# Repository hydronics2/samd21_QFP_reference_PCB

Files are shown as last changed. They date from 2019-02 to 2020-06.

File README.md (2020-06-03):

# samd21_QFP_reference_PCB

This is a reference design for a SAMD21 for easy SWD programming and testing.  This layout should work with any SAMD21 QFP package. The QFP package is pretty easy to solder and gives you about the same amount of pins as the original Aruduino 328P. The following SAMD21 packages are QFP:
- SAMD21E15 32kB of Flash **(read this)
- SAMD21E16 64kB of flash **(read this)
- SAMD21E17 128kB of flash
- SAMD21E18 256kB of flash

I made a specific reference board for the SAMD21G [posted here](https://github.com/hydronics2/2020-samd21_QFP_Reference) used in the Adafruit ItsyBitsy M0.

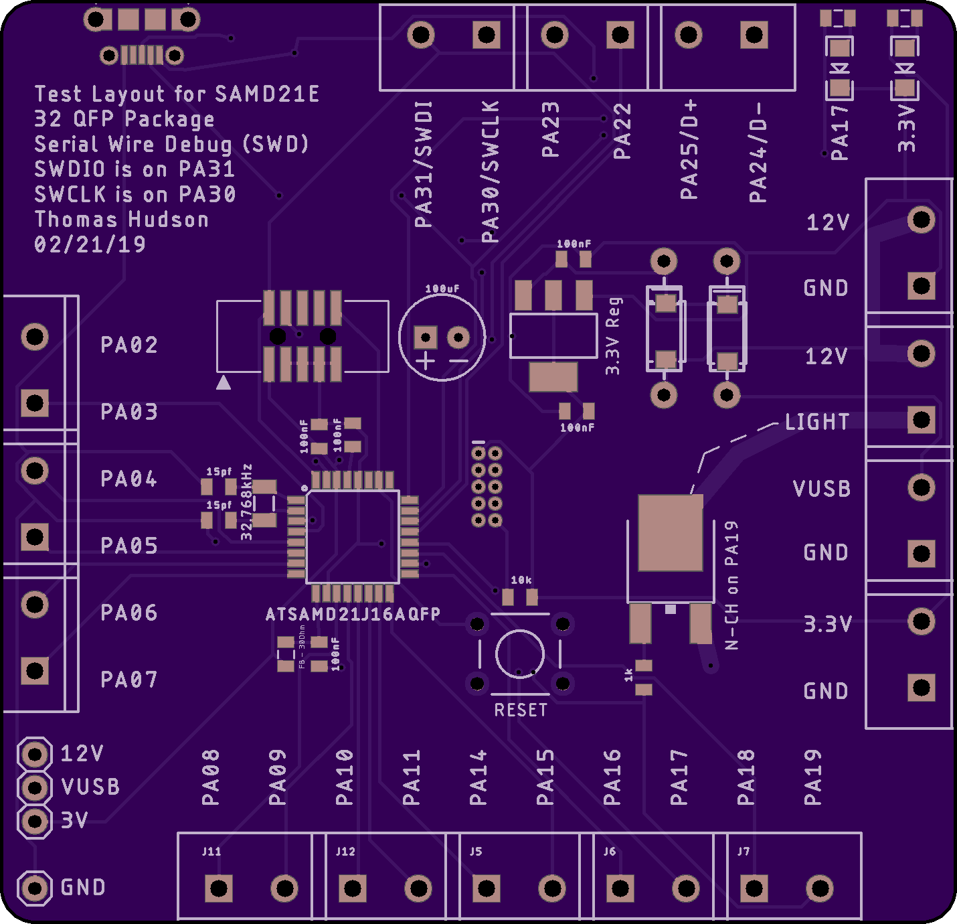
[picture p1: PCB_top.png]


I wanted to start to try SWD programming and these are the less expensive version of the popular SAMD21G on Adafruit and Sparkfun boards.
This PCB design relies heavily on Adafruit and Sparkfun reference design. I realized Adafruit has a similar design for their [32pin Trinket](https://learn.adafruit.com/assets/45723). They do not have a 32.768 crystal or a ferrite bead as recommended by Atmel. Not sure why/how that works. Instead of running the two pins PA00/PA01 to a crystal, they run them to their Dotstar LED!

You can order boards from Oshpark using this link: [project](https://oshpark.com/shared_projects/EjZP7lWQ)

Here's a list of parts:

- ATSAMD21E15B from [digikey](https://www.digikey.com/product-detail/en/microchip-technology/ATSAMD21E15B-AFT/1611-ATSAMD21E15B-AFTCT-ND/6832773). Don't get the ATSAMD21E15L!... the pinout is slightly different.
- generic 10 pin SWD Header from [mouser](https://www.mouser.com/ProductDetail/485-752)
- generic 5.08mm pitch screw headers (or 5mm)
- 	FIXED IND 10UH 500MA 300 MOHM [digikey](https://www.digikey.com/product-detail/en/tdk-corporation/MLZ2012N100LT000/445-6762-1-ND/2523583)
- 3.3V Regulator (18V max input) [mouser](https://www.mouser.com/ProductDetail/511-LDL1117S50R)
- T0-252-3 Mosfet (not needed) [mouser](https://www.mouser.com/ProductDetail/ON-Semiconductor-Fairchild/FDD8780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)
- USB micro connector [digikey](https://www.digikey.com/product-detail/en/amphenol-icc-fci/10118194-0001LF/609-4618-1-ND/2785382)
- standard 6mmx6mm tactile button [sparkfun](https://www.sparkfun.com/products/97)
- screw terminal 5mm pitch [sparkfun](https://www.sparkfun.com/products/8432) or [aliexpress](https://www.aliexpress.com/wholesale?catId=0&initiative_id=SB_20190221221755&SearchText=pcb+screw+terminal)
- input protection diodes on the 12V and USB input into the regulator. This is Adafruit's design. [digikey](https://www.digikey.com/product-detail/en/diodes-incorporated/B130-13-F/B130-FDICT-ND/815318)
- 32.768khz crystal (if needed, see above trinket design) [digikey](https://www.digikey.com/product-detail/en/epson/FC-135-32.7680KA-AG3/SER4086DKR-ND/6132726)
- crystal capacitors C7/C8 based on a 7pf load from the above crystal and assumed 2pf stray capacitence, CX1 = CX2 = 2(7pF - 2pF) = 10pF [digikey](https://www.digikey.com/product-detail/en/wurth-electronics-inc/885012006051/732-7793-1-ND/5454420)

SWD Programmer/Debugger: [Segger](https://www.digikey.com/product-detail/en/segger-microcontroller-systems/8.08.91-J-LINK-EDU-MINI/899-1061-ND/7387472)

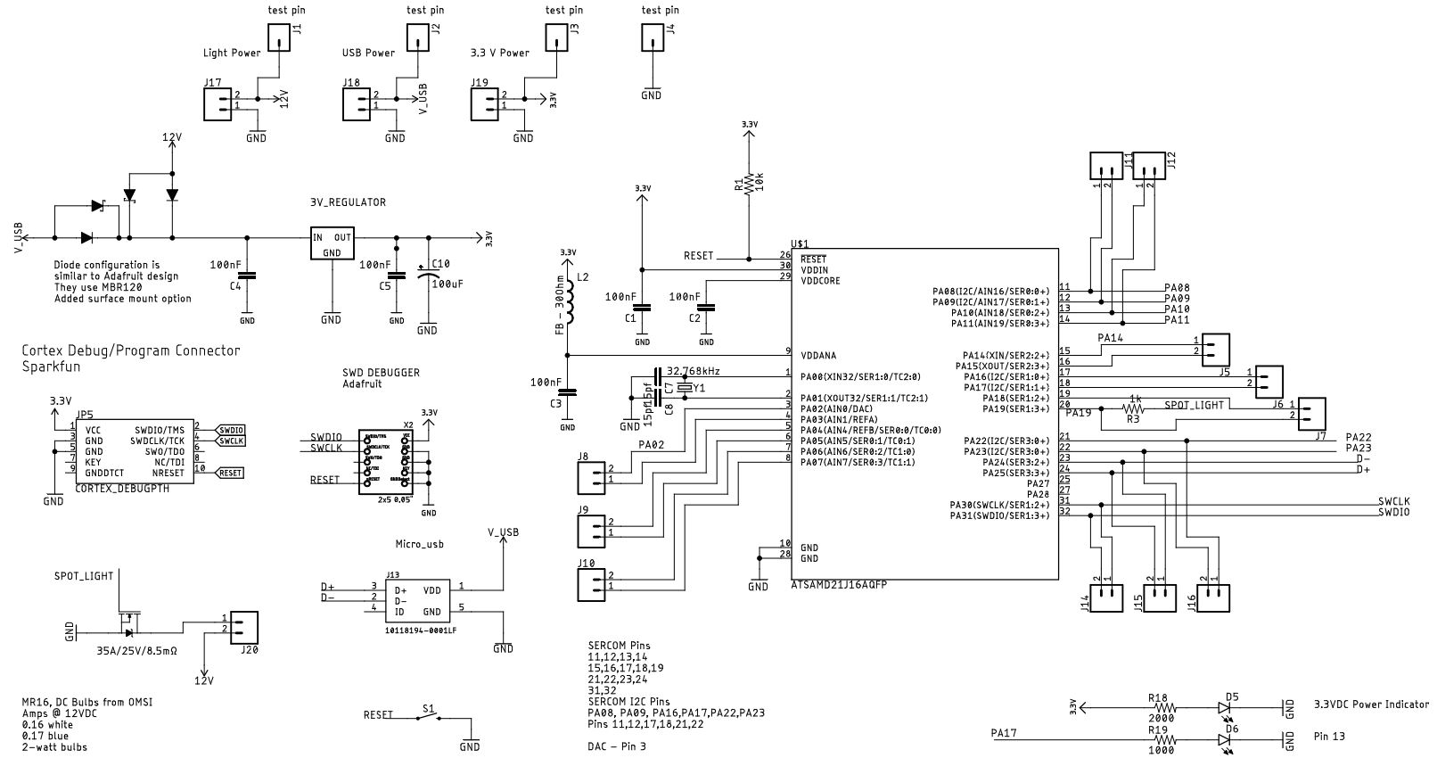
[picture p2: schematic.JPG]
schematic


Notes:
- add a ground plane
- chagne the silkscreen to SAMD21E15
- change the silkscreen C7/C8 from 15pf to 10pf

**READ THIS

The SAMD21E15 only has 32kb of flash. Fine for 8bit architecture but not for 32bit SAMD21 architecture!!
About 50 lines of simple code uses 332 bytes (12%) in for the UNO but compiles over 9,000 bytes (9248 bytes (56%)) for the SAMD21E15, SAMD21E16, SAMD21E17, etc

That means that I should have gone with the SAMD21E17 or SAMD21E18 with 128 or 256kb respectively.

[westf wrote this on the Arduino forum](https://forum.arduino.cc/index.php?topic=602377.msg4091161#msg4091161)... That's not as bad as it sounds - a sketch has a fair about of "fixed overhead" (an empty Zero sketch is 10k.)
So you're seeing THAT rather than some huge "50 lines of code bloats to 9k of code" multiplier for 32bit RISC.   You should be able to fit a pretty significant sketch into the 10k you have left...
But yeah, most ARM libraries (not just the Arduino code, BTW) pretty much assume that you'll have lots of memory, and don't bother being very inefficient.  (adding a tiny bit of floating point will use up another 9k.)
(and 8k for a bootloader?  Sheesh!)

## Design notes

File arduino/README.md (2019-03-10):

drop the hardware folder in your arduino folder next to the libraries folder.  Open the Arduino application and the SAMD21E15 shows up as a board option.... You can then compile code for the SAMD21E15.

There is no bootloader so you need a Segger or ATMEL programmer to SWD program the device.

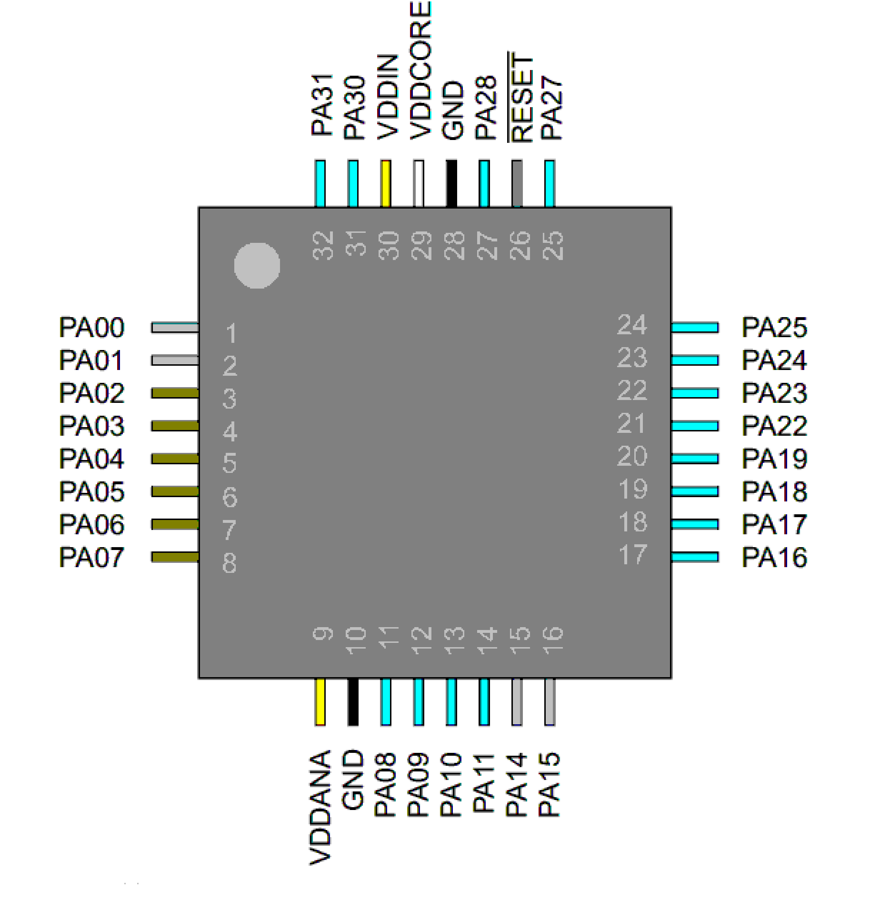
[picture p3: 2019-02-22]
SAMD21-QFP_4x.bmp

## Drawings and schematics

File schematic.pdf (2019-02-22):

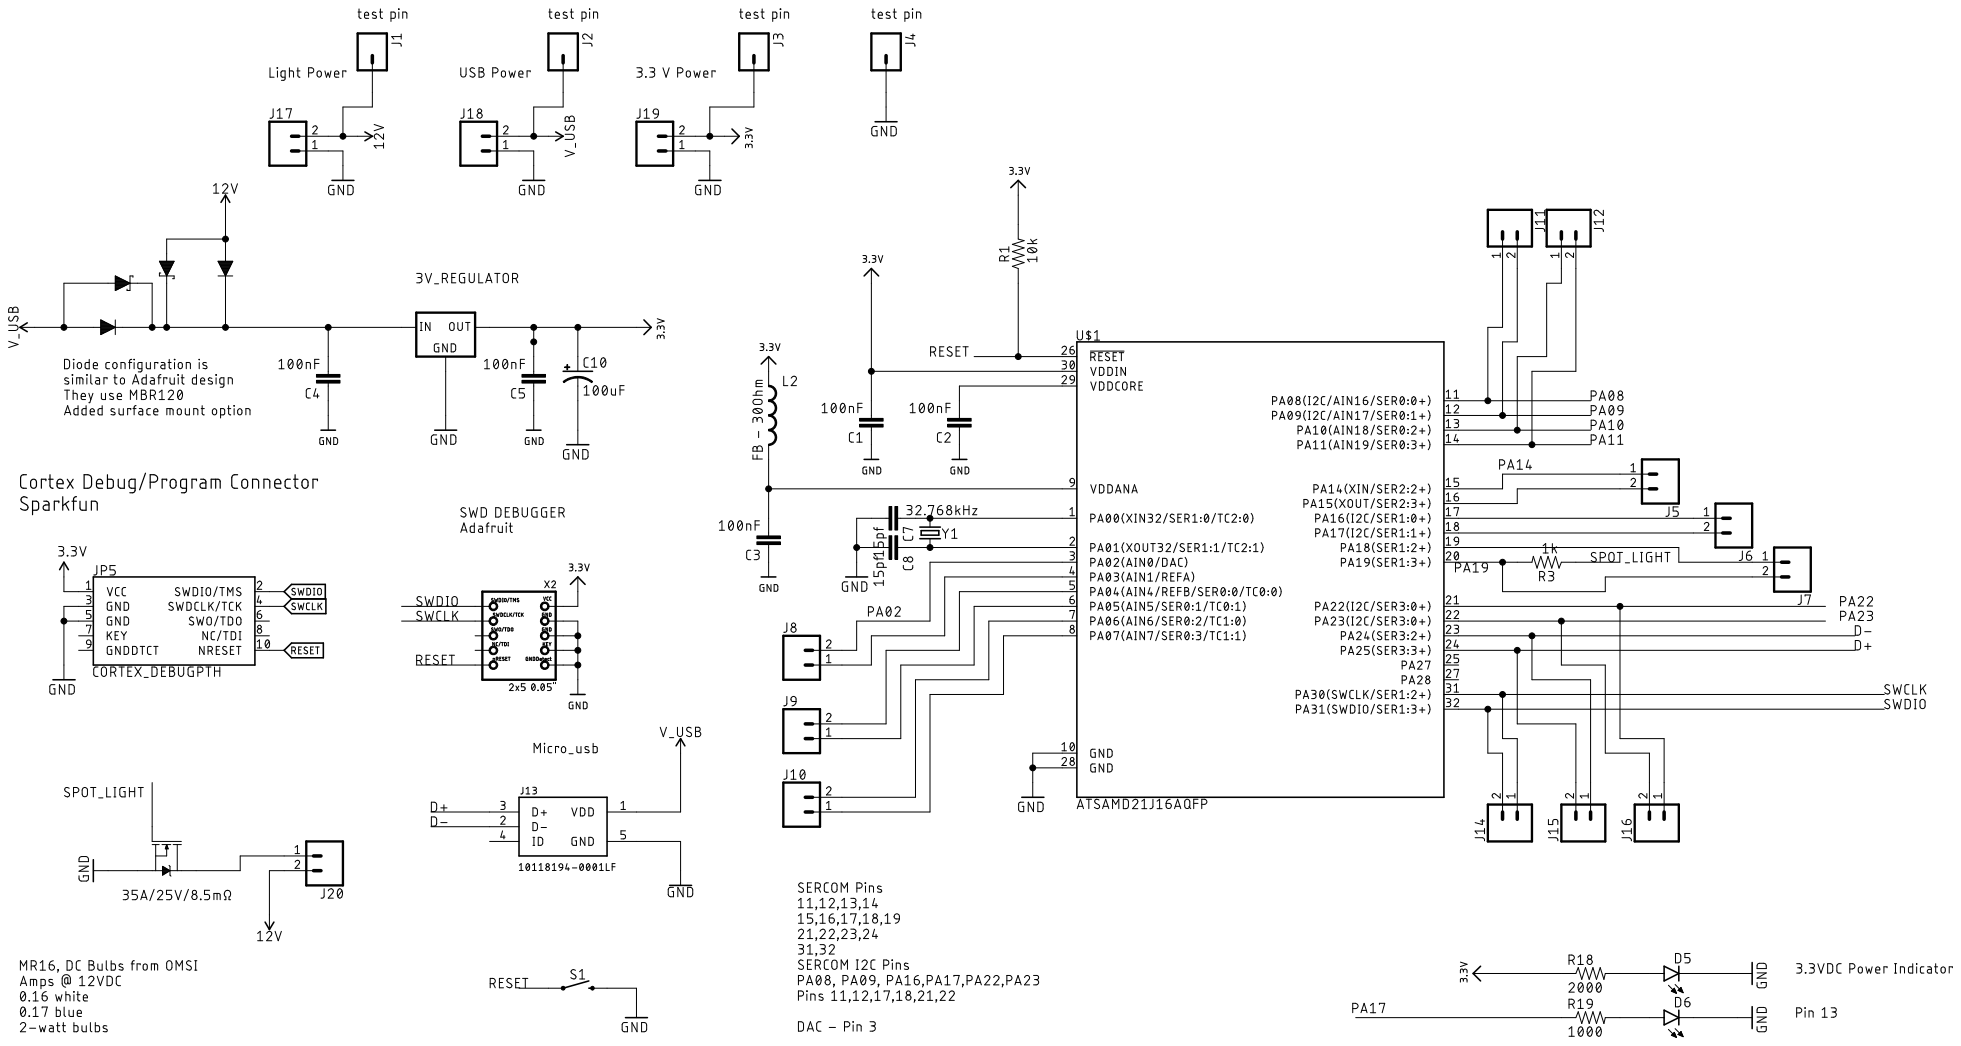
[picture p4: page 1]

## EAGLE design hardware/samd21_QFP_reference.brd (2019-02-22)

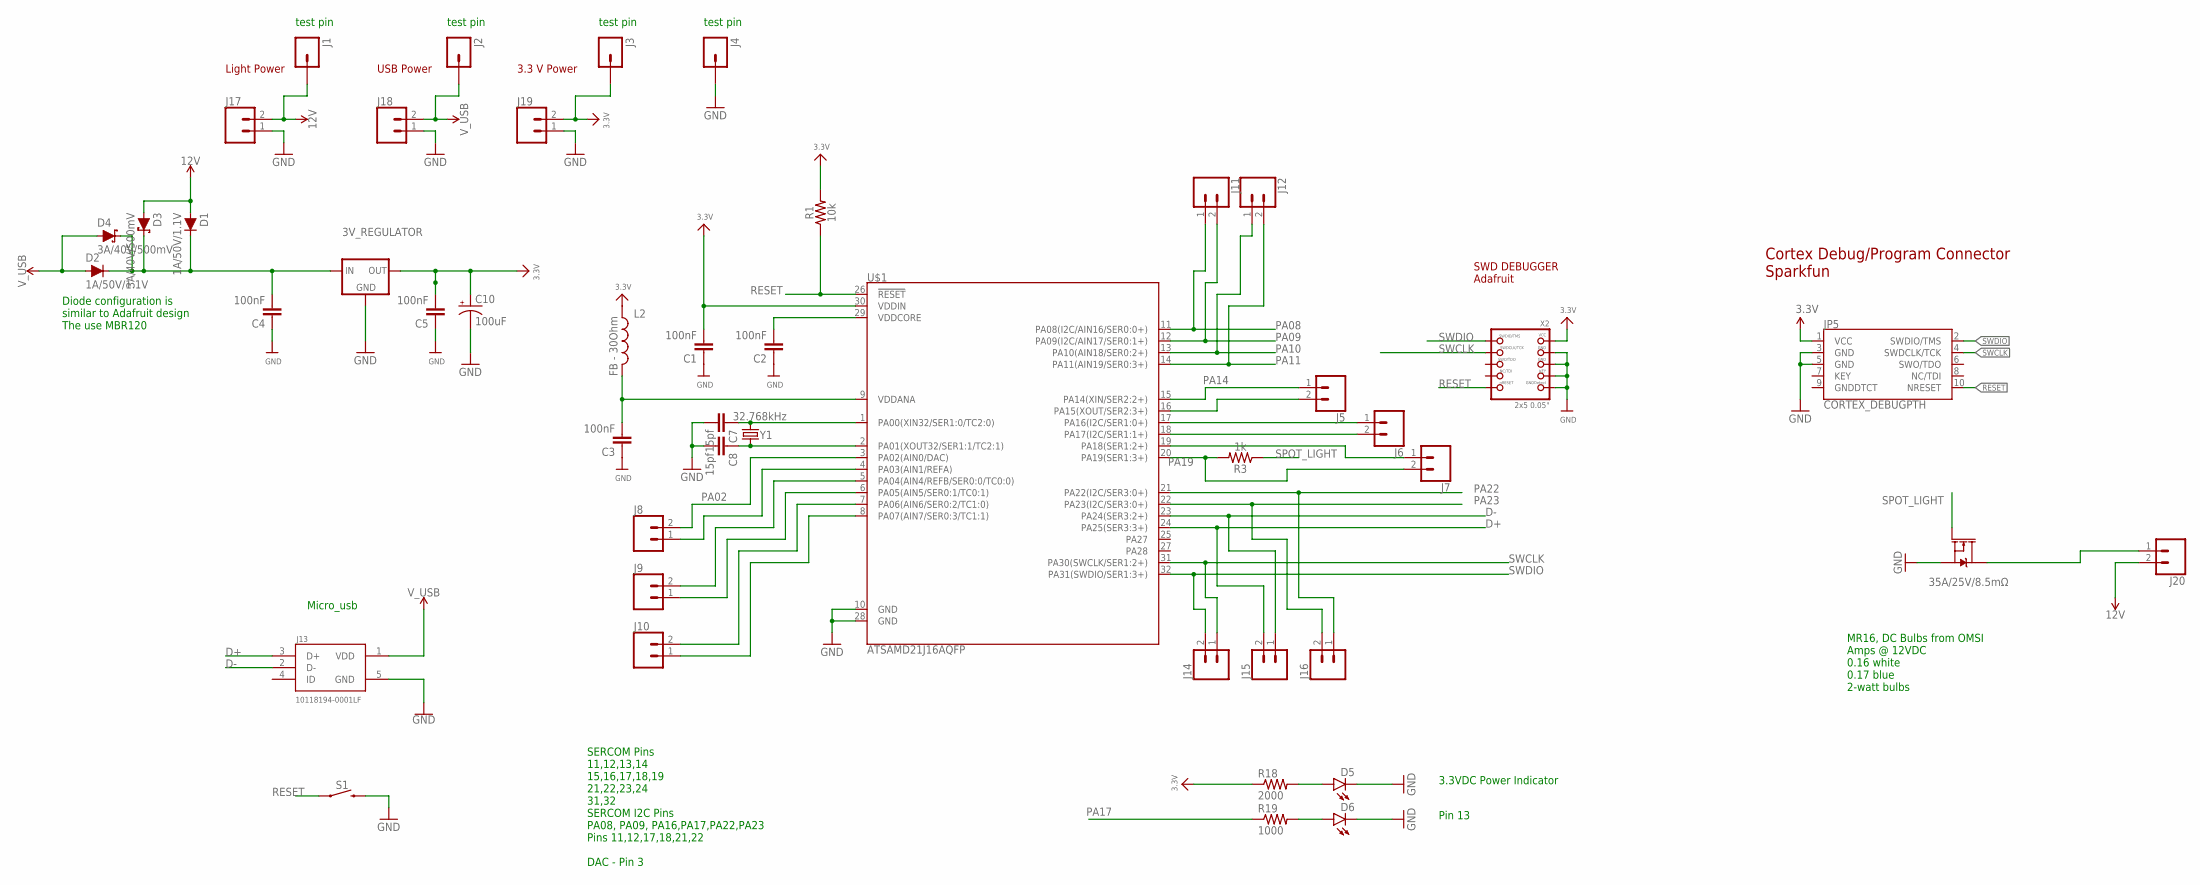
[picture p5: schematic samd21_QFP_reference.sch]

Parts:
3V_REGULATOR: LDL1117_5V_REG; SOT223
C1, C2, C3, C4, C5: 100nF; 0805
C7, C8: 15pf; 0805
C10: 100uF; CPOL-RADIAL-2.5MM-6.5MM
D1, D2: 1A/50V/1.1V; DIODE-1N4001
D3, D4: 3A/40V/500mV; SMA-DIODE
D5, D6: LED1206; LED-1206
J1, J2, J3, J4: M01PTH; 1X01
J5, J6, J7, J8, J9, J10, J11, J12, J14, J15, J16, J17, J18, J19, J20: CONN_025MM; SCREWTERMINAL-5MM-2
J13: 10118194-0001LF; FRAMATOME_10118194-0001LF
JP5: CORTEX_DEBUGPTH; 2X5-PTH-1.27MM
L2: FB - 30Ohm; 0805@1
Q1: 35A/25V/8.5mΩ; DPAK
R1: 10k; 0805
R3: 1k; 0805
R18: 2000; 0805
R19: 1000; 0805
S1: MOMENTARY-SWITCH-SPST-PTH-6.0MM-KIT; TACTILE_SWITCH_PTH_6.0MM_KIT
U$1: ATSAMD21J16AQFP; TQFP32-08
X2: 2x5 0.05"; 2X05_1.27MM_BOX_POSTS
Y1: 32.768kHz; CRYSTAL-SMD-3.2X1.5MM

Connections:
3.3V: 3V_REGULATOR.2 (OUT), 3V_REGULATOR.4 (OUT), C1.2, C5.2, C10.1 (+), J3.1, J19.2, JP5.1 (VCC), L2.1, R1.2, R18.1, U$1.30 (VDDIN), X2.1 (VCC)
12V: D1.A, D3.A, J1.1, J17.2, J20.2
D+: J13.3 (D+), J15.2, U$1.24 (PA25(SER3:3+))
D-: J13.2 (D-), J15.1, U$1.23 (PA24(SER3:2+))
GND: 3V_REGULATOR.1 (GND), C1.1, C2.1, C3.1, C4.1, C5.1, C7.2, C8.2, C10.2 (-), D5.C, D6.C, J4.1, J13.5 (GND), J17.1, J18.1, J19.1, JP5.3 (GND), JP5.5 (GND), Q1.3 (S), S1.3 (2), U$1.10 (GND), U$1.28 (GND), X2.3 (GND), X2.5 (GND), X2.7 (KEY), X2.9 (GNDDETECT)
unnamed: C3.2, L2.2, U$1.9 (VDDANA)
unnamed: C7.1, U$1.1 (PA00(XIN32/SER1:0/TC2:0)), Y1.P$2 (2)
unnamed: C2.2, U$1.29 (VDDCORE)
unnamed: C8.1, U$1.2 (PA01(XOUT32/SER1:1/TC2:1)), Y1.P$1 (1)
unnamed: 3V_REGULATOR.3 (IN), C4.2, D1.C, D2.C, D3.C, D4.C
unnamed: J20.1, Q1.4 (D)
unnamed: D5.A, R18.2
unnamed: D6.A, R19.2
PA02: J8.2, U$1.3 (PA02(AIN0/DAC))
PA03: J8.1, U$1.4 (PA03(AIN1/REFA))
PA04: J9.2, U$1.5 (PA04(AIN4/REFB/SER0:0/TC0:0))
PA05: J9.1, U$1.6 (PA05(AIN5/SER0:1/TC0:1))
PA06: J10.2, U$1.7 (PA06(AIN6/SER0:2/TC1:0))
PA07: J10.1, U$1.8 (PA07(AIN7/SER0:3/TC1:1))
PA08: J11.1, U$1.11 (PA08(I2C/AIN16/SER0:0+))
PA09: J11.2, U$1.12 (PA09(I2C/AIN17/SER0:1+))
PA10: J12.1, U$1.13 (PA10(AIN18/SER0:2+))
PA11: J12.2, U$1.14 (PA11(AIN19/SER0:3+))
PA14: J5.1, U$1.15 (PA14(XIN/SER2:2+))
PA15: J5.2, U$1.16 (PA15(XOUT/SER2:3+))
PA16: J6.1, U$1.17 (PA16(I2C/SER1:0+))
PA17: J6.2, R19.1, U$1.18 (PA17(I2C/SER1:1+))
PA18: J7.1, U$1.19 (PA18(SER1:2+))
PA19: J7.2, R3.2, U$1.20 (PA19(SER1:3+))
PA22: J16.1, U$1.21 (PA22(I2C/SER3:0+))
PA23: J16.2, U$1.22 (PA23(I2C/SER3:0+))
RESET: JP5.10 (NRESET), R1.1, S1.1, U$1.26 (!RESET!), X2.10 (NRESET)
SPOT_LIGHT: Q1.1 (G), R3.1
SWCLK: J14.1, JP5.4 (SWDCLK/TCK), U$1.31 (PA30(SWCLK/SER1:2+)), X2.4 (SWDCLK)
SWDIO: J14.2, JP5.2 (SWDIO/TMS), U$1.32 (PA31(SWDIO/SER1:3+)), X2.2 (SWDIO)
V_USB: D2.A, D4.A, J2.1, J13.1 (VDD), J18.2

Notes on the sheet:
SWD DEBUGGER Adafruit
Cortex Debug/Program Connector Sparkfun
SERCOM Pins 11,12,13,14 15,16,17,18,19 21,22,23,24 31,32 SERCOM I2C Pins PA08, PA09, PA16,PA17,PA22,PA23 Pins 11,12,17,18,21,22 DAC - Pin 3
Micro_usb
MR16, DC Bulbs from OMSI Amps @ 12VDC 0.16 white 0.17 blue 2-watt bulbs
Light Power
USB Power
3.3 V Power
Diode configuration is similar to Adafruit design The use MBR120
3.3VDC Power Indicator
Pin 13
test pin

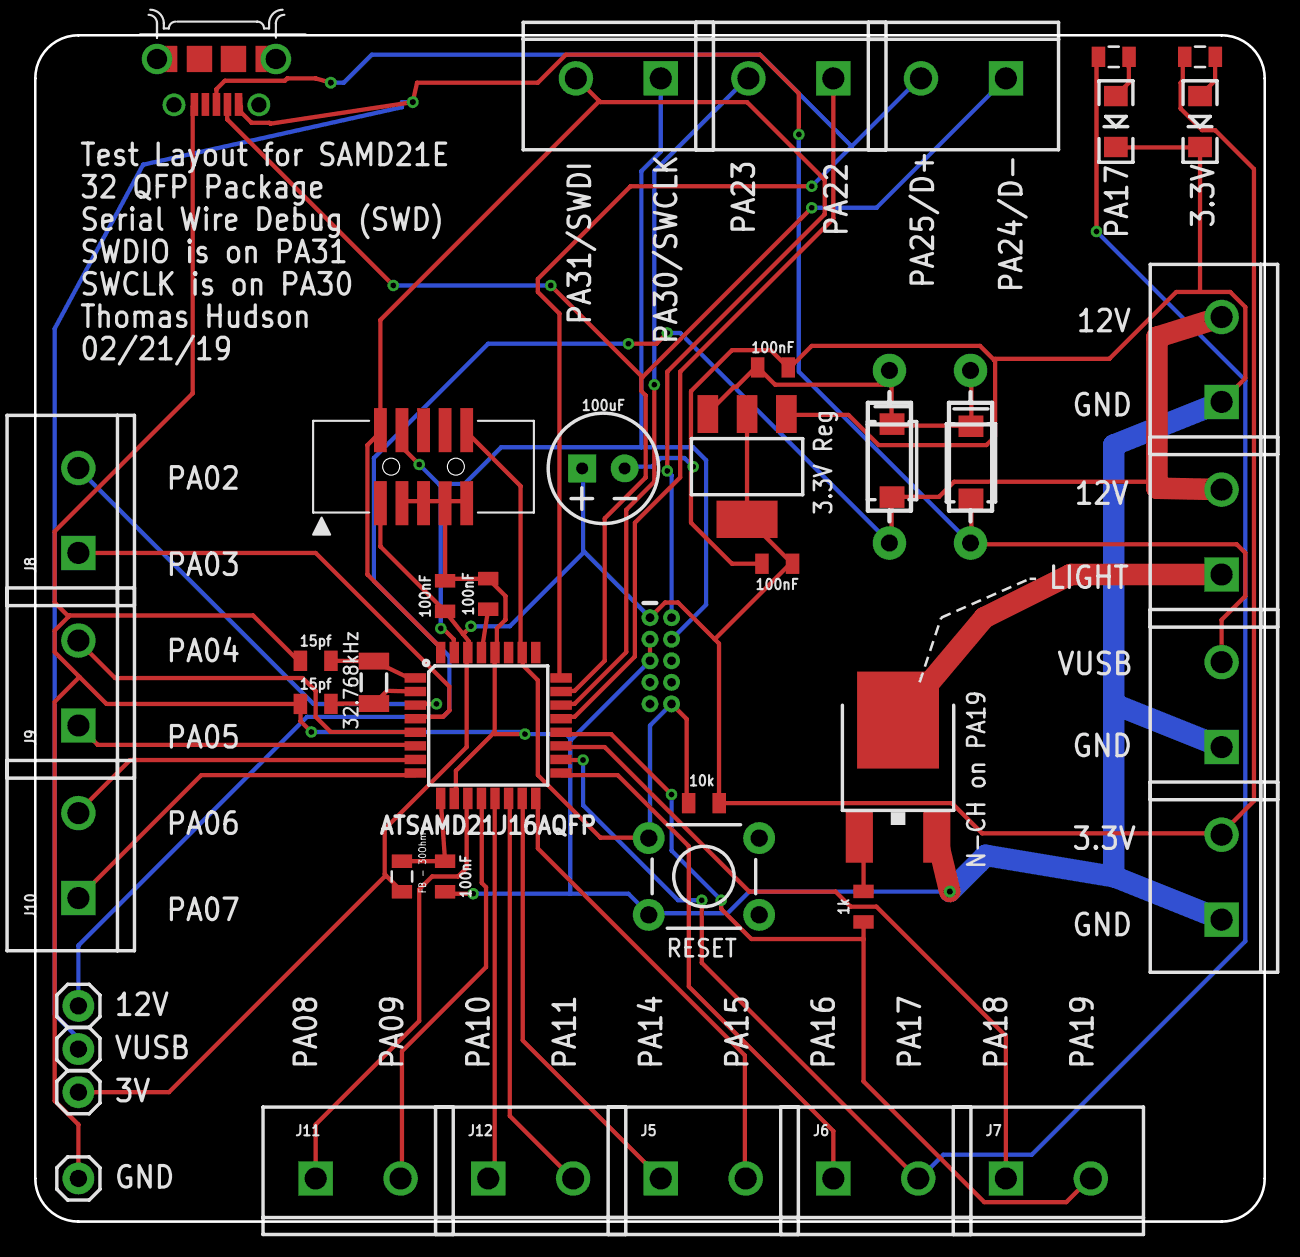
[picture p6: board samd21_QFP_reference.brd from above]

Board: 2 copper layers, 72.4 x 69.9 mm, 46 parts (0 on the bottom side), 36 nets.

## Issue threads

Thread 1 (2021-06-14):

Not a issue but more of a question.

Therealjosephchrzempiec, 2021-06-14:
Hello, Do I need to put this into the same documents folder next to the libraries, sketches or do i need to add this in the C prpgram files in the arduino hardware folder. Or the last place is the C username local appdata arduino15 folder to make this chip work?
I have the same chip as you do mine is a ATSAMD21E15B-AU version. Would this work?

Joseph

Therealjosephchrzempiec, 2021-06-14:
Hello, Okay this became a issue now for me. I have put the folder in the Documents/Arduino Folder right with the libraries and sketches. Then i open arduino and saw it in the Boards area. So i selected it and upload the blink sketch and came up with this error.

Sketch uses 10792 bytes (65%) of program storage space. Maximum is 16384 bytes.
Global variables use 1984 bytes of dynamic memory.
Open On-Chip Debugger 0.10.0+dev-gf0767a31 (2018-06-11-13:36)
Licensed under GNU GPL v2
For bug reports, read
	http://openocd.org/doc/doxygen/bugs.html
debug_level: 0
embedded:startup.tcl:60: Error: Can't find C:\Users\jJc\Documents\Arduino\hardware\my_boards\samd/variants/samd21e15/{build.openocdscript}
in procedure 'script'
at file "embedded:startup.tcl", line 60
the selected serial port at file "embedded:startup.tcl", line 60
 does not exist or your board is not connected

Therealjosephchrzempiec, 2021-06-14:
I havd tried to burn the bootloader and i got this error message. Error while burning bootloader: missing 'bootloader.tool' configuration parameter

Joseph

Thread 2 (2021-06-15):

Simple led blink.

Therealjosephchrzempiec, 2021-06-15:
Hello i have upload your board file in hardware within the arduino folder. Everything took so far with a lot of help from the arduino community mostly Pert helped me. So i mange to get a upload of the board however when i tried a simple led blink i got nothing. I have tried all pins and even change digital pins  nothing is working. I'm unsure if I'm missing something. Can someone please help me? I'm using the SamD21E15B processor. I'm not aure what is going on. also in you variant.cpp file you have two going to pa17 for d12 and d13. Can someone please help me?

Joseph

Therealjosephchrzempiec, 2021-06-15:
Hello can someone please help me?

Joseph

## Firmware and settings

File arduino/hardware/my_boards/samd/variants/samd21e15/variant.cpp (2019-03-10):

/*
  Copyright (c) 2014-2015 Arduino LLC.  All right reserved.

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
  You should have received a copy of the GNU Lesser General Public
  License along with this library; if not, write to the Free Software
  Foundation, Inc., 51 Franklin St, Fifth Floor, Boston, MA  02110-1301  USA
*/
/*
 * +------------+------------------+--------+-----------------+--------------------------------------------------------------------------------------------------------
 * + Pin number + Gemma Board pin  |  PIN   | Label/Name      | Comments (* is for default peripheral in use)
 * +------------+------------------+--------+-----------------+--------------------------------------------------------------------------------------------------------
 * |            | Digital Low      |        |                 |
 * +------------+------------------+--------+-----------------+--------------------------------------------------------------------------------------------------------
 * | 0          | D0               |  PA04  | D0/A2/SDA/TX    | EIC/EXTINT[4]  ADC/AIN[4]  AC/AIN[0] PTC/Y[2]  SERCOM0/PAD[0]                  *TCC0/WO[0]
 * | 1          | D1               |  PA02  | D1/A0/VOUT      | EIC/EXTINT[2]  ADC/AIN[0] *DAC/VOUT  PTC/Y[0]
 * | 2          | D2               |  PA05  | D2/A1/SCL/RX    | EIC/EXTINT[5]  ADC/AIN[5]  AC/AIN[1] PTC/Y[5]  SERCOM0/PAD[1]                  *TCC0/WO[1]
 * | 3          | Dotstar Data     |  PA00  |                 |
 * | 4          | DotStar Clock    |  PA01  |                 |
 * +------------+------------------+--------+-----------------+--------------------------------------------------------------------------------------------------------
 * |            | USB              |        |                 |
 * +------------+------------------+--------+-----------------+--------------------------------------------------------------------------------------------------------
 * | 5          |                  |  PA28  | USB_HOST_ENABLE | EIC/EXTINT[8]
 * | 6          |                  |  PA24  | USB_NEGATIVE    | *USB/DM
 * | 7          |                  |  PA25  | USB_POSITIVE    | *USB/DP
 * +------------+------------------+--------+-----------------+--------------------------------------------------------------------------------------------------------
 * |            | Analog Pins      |        |                 |
 * +------------+------------------+--------+-----------------+--------------------------------------------------------------------------------------------------------
 * | 8          | A0               |  PA02  | D1/A0/VOUT      | EIC/EXTINT[2] *ADC/AIN[0]  DAC/VOUT  PTC/Y[0]
 * | 9          | A1               |  PA05  | D2/A1/SCL/RX    | EIC/EXTINT[5] *ADC/AIN[5]  AC/AIN[1] PTC/Y[5]  SERCOM0/PAD[1]                  TCC0/WO[1]
 * | 10         | A2               |  PA04  | D0/A2/SDA/TX    | EIC/EXTINT[4] *ADC/AIN[4]  AC/AIN[0] PTC/Y[2]  SERCOM0/PAD[0]                  TCC0/WO[0]
 * +------------+------------------+--------+-----------------+--------------------------------------------------------------------------------------------------------
 * |            | SWD              |        |                 |
 * +------------+------------------+--------+-----------------+--------------------------------------------------------------------------------------------------------
 * | 11         |                  |  PA30  | SWD Clock       |
 * | 12         |                  |  PA31  | SWD Data        |
 * +------------+------------------+--------+-----------------+--------------------------------------------------------------------------------------------------------
 * |            | Digital High     |        |                 |
 * +------------+------------------+--------+-----------------+--------------------------------------------------------------------------------------------------------
 * | 13         | 13               |  PA23  | LED             | EIC/EXTINT[7]                        PTC/X[11] *SERCOM3/PAD[1] SERCOM5/PAD[1] TC4/WO[1] TCC0/WO[5]
 * | 14         | 14               |  PA10  | RXLED           | EIC/EXTINT[10] ADC/AIN[18]           PTC/X[2] *SERCOM0/PAD[2]                  TCC0/WO[2]  TCC1/WO[0]
 * | 15         | 15               |  PA11  | TXLED           | EIC/EXTINT[11] ADC/AIN[19]           PTC/X[3] *SERCOM0/PAD[3]  SERCOM2/PAD[3]  TCC0/WO[3]  TCC1/WO[1]
 * +------------+------------------+--------+-----------------+--------------------------------------------------------------------------------------------------------
 */

#include "variant.h"

/*
 * Pins descriptions
 */
const PinDescription g_APinDescription[]=
{
  // GPIO 0-4 on external pads
  // D0, ADC, PWM, IRQ, and I2C SDA on sercom2 - no captouch
  { PORTA,  8, PIO_SERCOM_ALT, (PIN_ATTR_DIGITAL|PIN_ATTR_PWM|PIN_ATTR_TIMER), ADC_Channel16, PWM0_CH0, TCC0_CH0, EXTERNAL_INT_NMI },  // TCC0/WO[0]

  // D1, ADC, DAC, IRQ, Captouch and general purpose pin - no timer
  { PORTA,  2, PIO_ANALOG, PIN_ATTR_ANALOG, ADC_Channel0, NOT_ON_PWM, NOT_ON_TIMER, EXTERNAL_INT_2 }, // ADC/AIN[0]

  // D2, ADC, PWM, IRQ, and I2C SCL on sercom2 - no captouch
  { PORTA,  9, PIO_SERCOM_ALT, (PIN_ATTR_DIGITAL|PIN_ATTR_PWM|PIN_ATTR_TIMER), ADC_Channel17, PWM0_CH1, TCC0_CH1, EXTERNAL_INT_9 }, // TCC0/WO[1]

  // D3, ADC, PWM, IRQ, UART RX, Captouch and general purpose pin
  { PORTA,  7, PIO_SERCOM_ALT, (PIN_ATTR_DIGITAL|PIN_ATTR_PWM|PIN_ATTR_TIMER), ADC_Channel7, PWM1_CH1, TCC1_CH1, EXTERNAL_INT_7 }, // TCC1/WO[1]

  // D4, ADC, PWM, IRQ, UART TX, Captouch and general purpose pin
  { PORTA,  6, PIO_SERCOM_ALT, (PIN_ATTR_DIGITAL|PIN_ATTR_PWM|PIN_ATTR_TIMER), ADC_Channel6, PWM1_CH0, TCC1_CH0, EXTERNAL_INT_6 }, // TCC1/WO[0]

  // D5, same as D0 but on sercom2 (for SPI sercommin')
  { PORTA,  8, PIO_SERCOM, (PIN_ATTR_DIGITAL|PIN_ATTR_PWM|PIN_ATTR_TIMER), ADC_Channel16, PWM0_CH0, TCC0_CH0, EXTERNAL_INT_NMI },  // TCC0/WO[0]
  // D6, same as D2 but on sercom2 (for SPI sercommin')
  { PORTA,  9, PIO_SERCOM, (PIN_ATTR_DIGITAL|PIN_ATTR_PWM|PIN_ATTR_TIMER), ADC_Channel17, PWM0_CH1, TCC0_CH1, EXTERNAL_INT_9 }, // TCC0/WO[1]

  // GPIO 7 & 8 - DotStar internal data/clock
  // ----------------------------------------
  { PORTA,  0, PIO_DIGITAL, 0, ADC_Channel4, NOT_ON_PWM, NOT_ON_TIMER, EXTERNAL_INT_4 }, // ADC/AIN[4]
  { PORTA,  1, PIO_DIGITAL, 0, ADC_Channel5, NOT_ON_PWM, NOT_ON_TIMER, EXTERNAL_INT_5 }, // ADC/AIN[5]

  // GPIO 9, 10, 11 USB Host enable
  // ----------------------------
  { PORTA, 28, PIO_COM, PIN_ATTR_NONE, No_ADC_Channel, NOT_ON_PWM, NOT_ON_TIMER, EXTERNAL_INT_NONE }, // USB Host enable - GPIO #5
  { PORTA, 24, PIO_COM, PIN_ATTR_NONE, No_ADC_Channel, NOT_ON_PWM, NOT_ON_TIMER, EXTERNAL_INT_NONE }, // USB/DM - GPIO #6
  { PORTA, 25, PIO_COM, PIN_ATTR_NONE, No_ADC_Channel, NOT_ON_PWM, NOT_ON_TIMER, EXTERNAL_INT_NONE }, // USB/DP - GPIO #7
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

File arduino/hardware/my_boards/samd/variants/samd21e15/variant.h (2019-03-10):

/*
  Copyright (c) 2014-2015 Arduino LLC.  All right reserved.

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
  You should have received a copy of the GNU Lesser General Public
  License along with this library; if not, write to the Free Software
  Foundation, Inc., 51 Franklin St, Fifth Floor, Boston, MA  02110-1301  USA
*/

#ifndef _VARIANT_ARDUINO_ZERO_
#define _VARIANT_ARDUINO_ZERO_

// The definitions here needs a SAMD core >=1.6.6
#define ARDUINO_SAMD_VARIANT_COMPLIANCE 10606

/*----------------------------------------------------------------------------
 *        Definitions
 *----------------------------------------------------------------------------*/

/** Frequency of the board main oscillator */
#define VARIANT_MAINOSC		(32768ul)

/** Master clock frequency */
#define VARIANT_MCK			  (48000000ul)

/*----------------------------------------------------------------------------
 *        Headers
 *----------------------------------------------------------------------------*/

#include "WVariant.h"

#ifdef __cplusplus
#include "SERCOM.h"
#include "Uart.h"
#endif // __cplusplus

#ifdef __cplusplus
extern "C"
{
#endif // __cplusplus

/*----------------------------------------------------------------------------
 *        Pins
 *----------------------------------------------------------------------------*/

// Number of pins defined in PinDescription array
#define PINS_COUNT           (22u)
#define NUM_DIGITAL_PINS     (22u)
#define NUM_ANALOG_INPUTS    (5u)
#define NUM_ANALOG_OUTPUTS   (1u)
#define analogInputToDigitalPin(p)  ((p < 5u) ? (p) + PIN_A0 : -1)

#define digitalPinToPort(P)        ( &(PORT->Group[g_APinDescription[P].ulPort]) )
#define digitalPinToBitMask(P)     ( 1 << g_APinDescription[P].ulPin )
//#define analogInPinToBit(P)        ( )
#define portOutputRegister(port)   ( &(port->OUT.reg) )
#define portInputRegister(port)    ( &(port->IN.reg) )
#define portModeRegister(port)     ( &(port->DIR.reg) )
#define digitalPinHasPWM(P)        ( g_APinDescription[P].ulPWMChannel != NOT_ON_PWM || g_APinDescription[P].ulTCChannel != NOT_ON_TIMER )

/*
 * digitalPinToTimer(..) is AVR-specific and is not defined for SAMD
 * architecture. If you need to check if a pin supports PWM you must
 * use digitalPinHasPWM(..).
 *
 * https://github.com/arduino/Arduino/issues/1833
 */
// #define digitalPinToTimer(P)

// LEDs
#define PIN_LED_13           (13u)
#define PIN_LED_RXL          (21u)
#define PIN_LED_TXL          (22u)
#define PIN_LED              PIN_LED_13
#define PIN_LED2             PIN_LED_RXL
#define PIN_LED3             PIN_LED_TXL
#define LED_BUILTIN          PIN_LED_13
// DotStar LED
#define INTERNAL_DS_DATA     7
#define INTERNAL_DS_CLK      8

/*
 * Analog pins
 */
#define PIN_A0               (14ul)
#define PIN_A1               (PIN_A0 + 1)
#define PIN_A2               (PIN_A0 + 2)
#define PIN_A3               (PIN_A0 + 3)
#define PIN_A4               (PIN_A0 + 4)
#define PIN_DAC0             PIN_A0

static const uint8_t A0  = PIN_A0;
static const uint8_t A1  = PIN_A1;
static const uint8_t A2  = PIN_A2;
static const uint8_t A3  = PIN_A3;
static const uint8_t A4  = PIN_A4;
static const uint8_t DAC0 = PIN_DAC0;

#define ADC_RESOLUTION		12

/*
 * Serial interfaces
 */

// Serial1 (sercom 0)
#define PIN_SERIAL1_RX       (3ul) // PA07
#define PAD_SERIAL1_RX       (SERCOM_RX_PAD_3)
#define PIN_SERIAL1_TX       (4ul) // PA06
#define PAD_SERIAL1_TX       (UART_TX_PAD_2)

/*
 * SPI Interfaces
 */
#define SPI_INTERFACES_COUNT 1 // shared with I2C/UART (can't do both)

#define PIN_SPI_MISO         (6u)  // PA09 same as D2
#define PIN_SPI_MOSI         (4u)
#define PIN_SPI_SCK          (3u)
#define PERIPH_SPI           sercom0
#define PAD_SPI_TX           SPI_PAD_2_SCK_3
#define PAD_SPI_RX           SERCOM_RX_PAD_1

static const uint8_t SS	  = 5 ;	// SERCOM0 last PAD is present on 5 but HW SS isn't used. Set here only for reference.
static const uint8_t MOSI = PIN_SPI_MOSI ;
static const uint8_t MISO = PIN_SPI_MISO ;
static const uint8_t SCK  = PIN_SPI_SCK ;

/*
 * Wire Interfaces
 */
#define WIRE_INTERFACES_COUNT 1

#define PIN_WIRE_SDA         (0u)
#define PIN_WIRE_SCL         (2u)
#define PERIPH_WIRE          sercom2
#define WIRE_IT_HANDLER      SERCOM2_Handler

static const uint8_t SDA = PIN_WIRE_SDA;
static const uint8_t SCL = PIN_WIRE_SCL;

/*
 * USB
 */
#define PIN_USB_HOST_ENABLE (9ul)
#define PIN_USB_DM          (10ul)
#define PIN_USB_DP          (11ul)

#ifdef __cplusplus
}
#endif

/*----------------------------------------------------------------------------
 *        Arduino objects - C++ only
 *----------------------------------------------------------------------------*/

#ifdef __cplusplus

/*	=========================
 *	===== SERCOM DEFINITION
 *	=========================
*/
extern SERCOM sercom0;
extern SERCOM sercom1;
extern SERCOM sercom2;
extern SERCOM sercom3;

extern Uart Serial1;

#endif

// These serial port names are intended to allow libraries and architecture-neutral
// sketches to automatically default to the correct port name for a particular type
// of use.  For example, a GPS module would normally connect to SERIAL_PORT_HARDWARE_OPEN,
// the first hardware serial port whose RX/TX pins are not dedicated to another use.
//
// SERIAL_PORT_MONITOR        Port which normally prints to the Arduino Serial Monitor
//
// SERIAL_PORT_USBVIRTUAL     Port which is USB virtual serial
//
// SERIAL_PORT_LINUXBRIDGE    Port which connects to a Linux system via Bridge library
//
// SERIAL_PORT_HARDWARE       Hardware serial port, physical RX & TX pins.
//
// SERIAL_PORT_HARDWARE_OPEN  Hardware serial ports which are open for use.  Their RX & TX
//                            pins are NOT connected to anything by default.
#define SERIAL_PORT_USBVIRTUAL      Serial
#define SERIAL_PORT_MONITOR         Serial
// Serial has no physical pins broken out, so it's not listed as HARDWARE port
#define SERIAL_PORT_HARDWARE        Serial1
#define SERIAL_PORT_HARDWARE_OPEN   Serial1

#endif /* _VARIANT_ARDUINO_ZERO_ */

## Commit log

2019-03-10 update board files
    [samd21_QFP_reference.brd, samd21_QFP_reference.sch]
2019-03-10 added all hardware Signed-off-by: thomas <hydronics@gmail.com>
    [arduino_zero.cfg, samd21_QFP_reference.brd, samd21_QFP_reference.sch]

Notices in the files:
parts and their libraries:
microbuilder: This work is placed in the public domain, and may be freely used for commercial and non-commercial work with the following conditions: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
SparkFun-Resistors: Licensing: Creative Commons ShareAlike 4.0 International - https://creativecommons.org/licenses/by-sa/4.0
